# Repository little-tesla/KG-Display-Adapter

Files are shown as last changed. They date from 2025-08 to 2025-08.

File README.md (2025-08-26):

# KG Display Adapter

A KiCAD-designed replacement adapter PCB for Keisoku Giken electronic loads (tested with **ELS-304**, likely compatible with similar models).

## Overview

This adapter allows the use of a modern **3.3V display module** as a replacement for the original LCD.

- **Compatible display:** [NHD-C12864WC-FSW-FBW-3V3](https://www.newhavendisplay.com/nhdc12864wcfswfbw3v3-p-6365.html)
- **Purpose:** Replaces the obsolete LCD

## Important Notes

- The new display is slightly thicker; during assembly, the **thin clear protective sheet** originally in front of the display must be **omitted**.
- The **original backlight LEDs must be removed**.
- The **adapter’s backlight** should be connected using **two wires** to the front panel PCB.

## Images

3D and PCB views of the adapter:

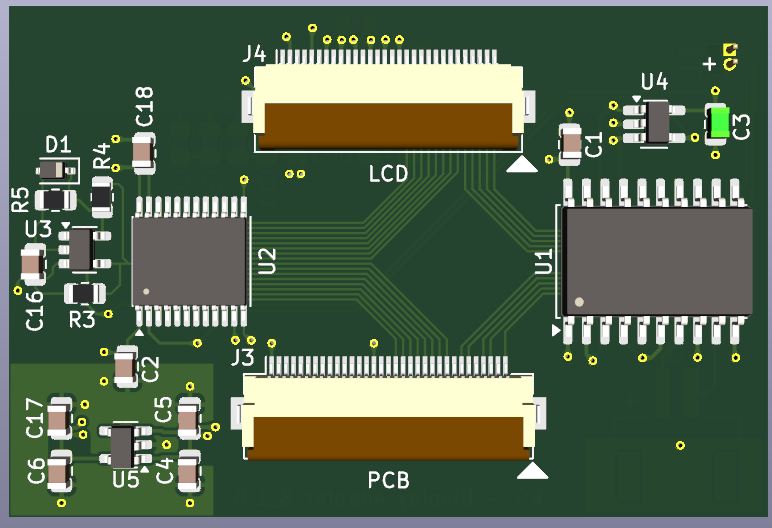
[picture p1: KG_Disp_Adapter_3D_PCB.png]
3D PCB

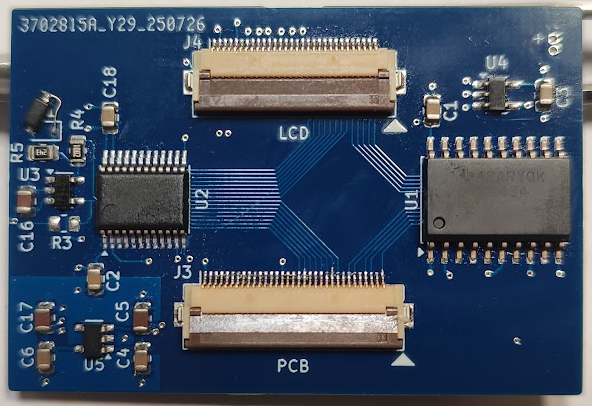
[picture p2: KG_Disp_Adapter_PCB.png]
PCB


Integration and connection to the front panel PCB and display:

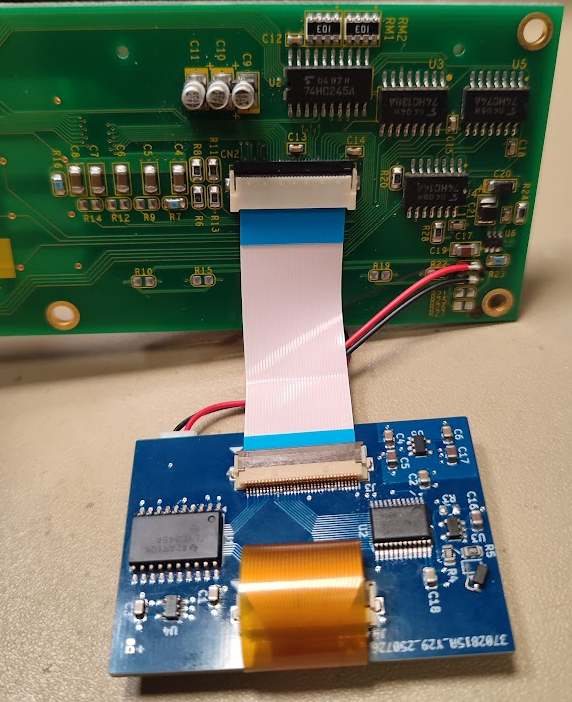
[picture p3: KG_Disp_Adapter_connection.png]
Connection

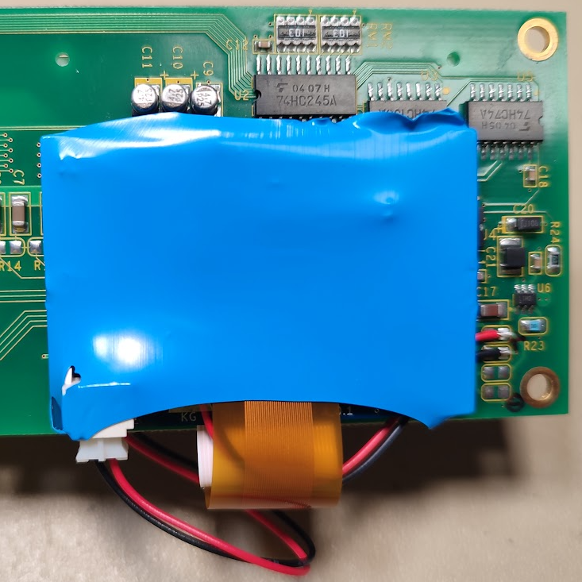
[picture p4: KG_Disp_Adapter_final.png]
Final Assembly


---

This project is shared for educational and hobbyist purposes. Use at your own risk.

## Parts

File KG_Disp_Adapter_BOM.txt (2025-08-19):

"Reference","Value","Datasheet","Footprint","Qty","DNP"
"C1,C2,C3,C4,C6,C18,C19","100n","~","Capacitor_SMD:C_0805_2012Metric","7",""
"C5,C17","10u","~","Capacitor_SMD:C_0805_2012Metric","2",""
"C7,C8,C9,C10,C11,C12,C13,C14,C15","1.5u","~","Capacitor_SMD:C_0805_2012Metric","9",""
"C16","4u7","~","Capacitor_SMD:C_0805_2012Metric","1",""
"D1","D","~","Diode_SMD:D_SOD-323","1",""
"J1","Conn_01x02","~","Connector_PinHeader_1.00mm:PinHeader_1x02_P1.00mm_Horizontal","1",""
"J2","CJT_A2001WR-S-2P_SMT","~","Library:CJT_A2001WR-S-2P_SMT_1x02-1MP_P2.00mm_Horizontal","1",""
"J3","FFC 33Pin, FH12-33S-0.5SH","~","Library:Hirose_FH12-33S-0.5SH_1x33-1MP_P0.50mm_Horizontal_reversed","1",""
"J4","FFC 30Pin, FH12-30S-0.5SH","~","Library:Hirose_FH12-30S-0.5SH_1x30-1MP_P0.50mm_Horizontal_Reversed","1",""
"R1,R2","160","~","Resistor_SMD:R_0805_2012Metric","2",""
"R4","10K","~","Resistor_SMD:R_0805_2012Metric","1",""
"R5","25K","~","Resistor_SMD:R_0805_2012Metric","1",""
"U1","SN74LVC245APW","https://www.ti.com/lit/ds/scas218x/scas218x.pdf","Package_SO:SOIC-20W_7.5x12.8mm_P1.27mm","1",""
"U2","SN74LVC8T245","https://www.ti.com/lit/ds/symlink/sn74lvc8t245.pdf","Package_SO:TSSOP-24_6.1x7.8mm_P0.65mm","1",""
"U3","SN74LVC1G14DBV","https://www.ti.com/lit/ds/symlink/sn74lvc1g14.pdf","Package_TO_SOT_SMD:SOT-23-5","1",""
"U4","NC7SZ32M5X","","Package_TO_SOT_SMD:SOT-23-5_HandSoldering","1",""
"U5","TLV73333PDBV","http://www.ti.com/lit/ds/symlink/tlv733p.pdf","Package_TO_SOT_SMD:SOT-23-5","1",""

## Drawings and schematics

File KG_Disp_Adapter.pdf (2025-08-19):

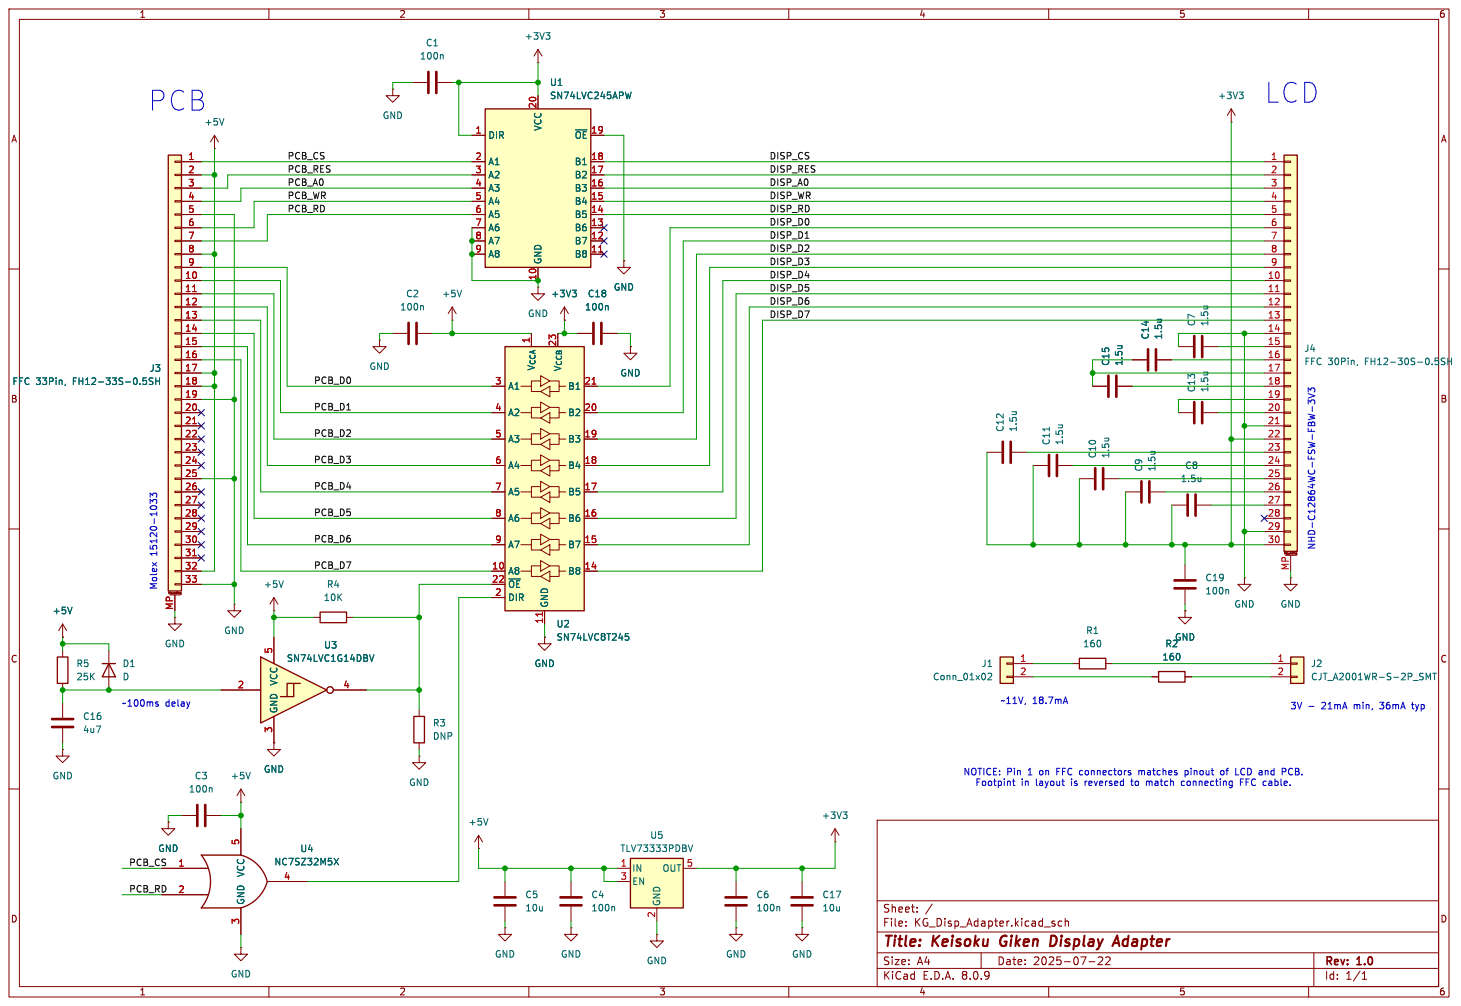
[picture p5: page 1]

Id: 1/1 Title: Keisoku Giken Display Adapter File: KG_Disp_Adapter.kicad_sch Sheet: /

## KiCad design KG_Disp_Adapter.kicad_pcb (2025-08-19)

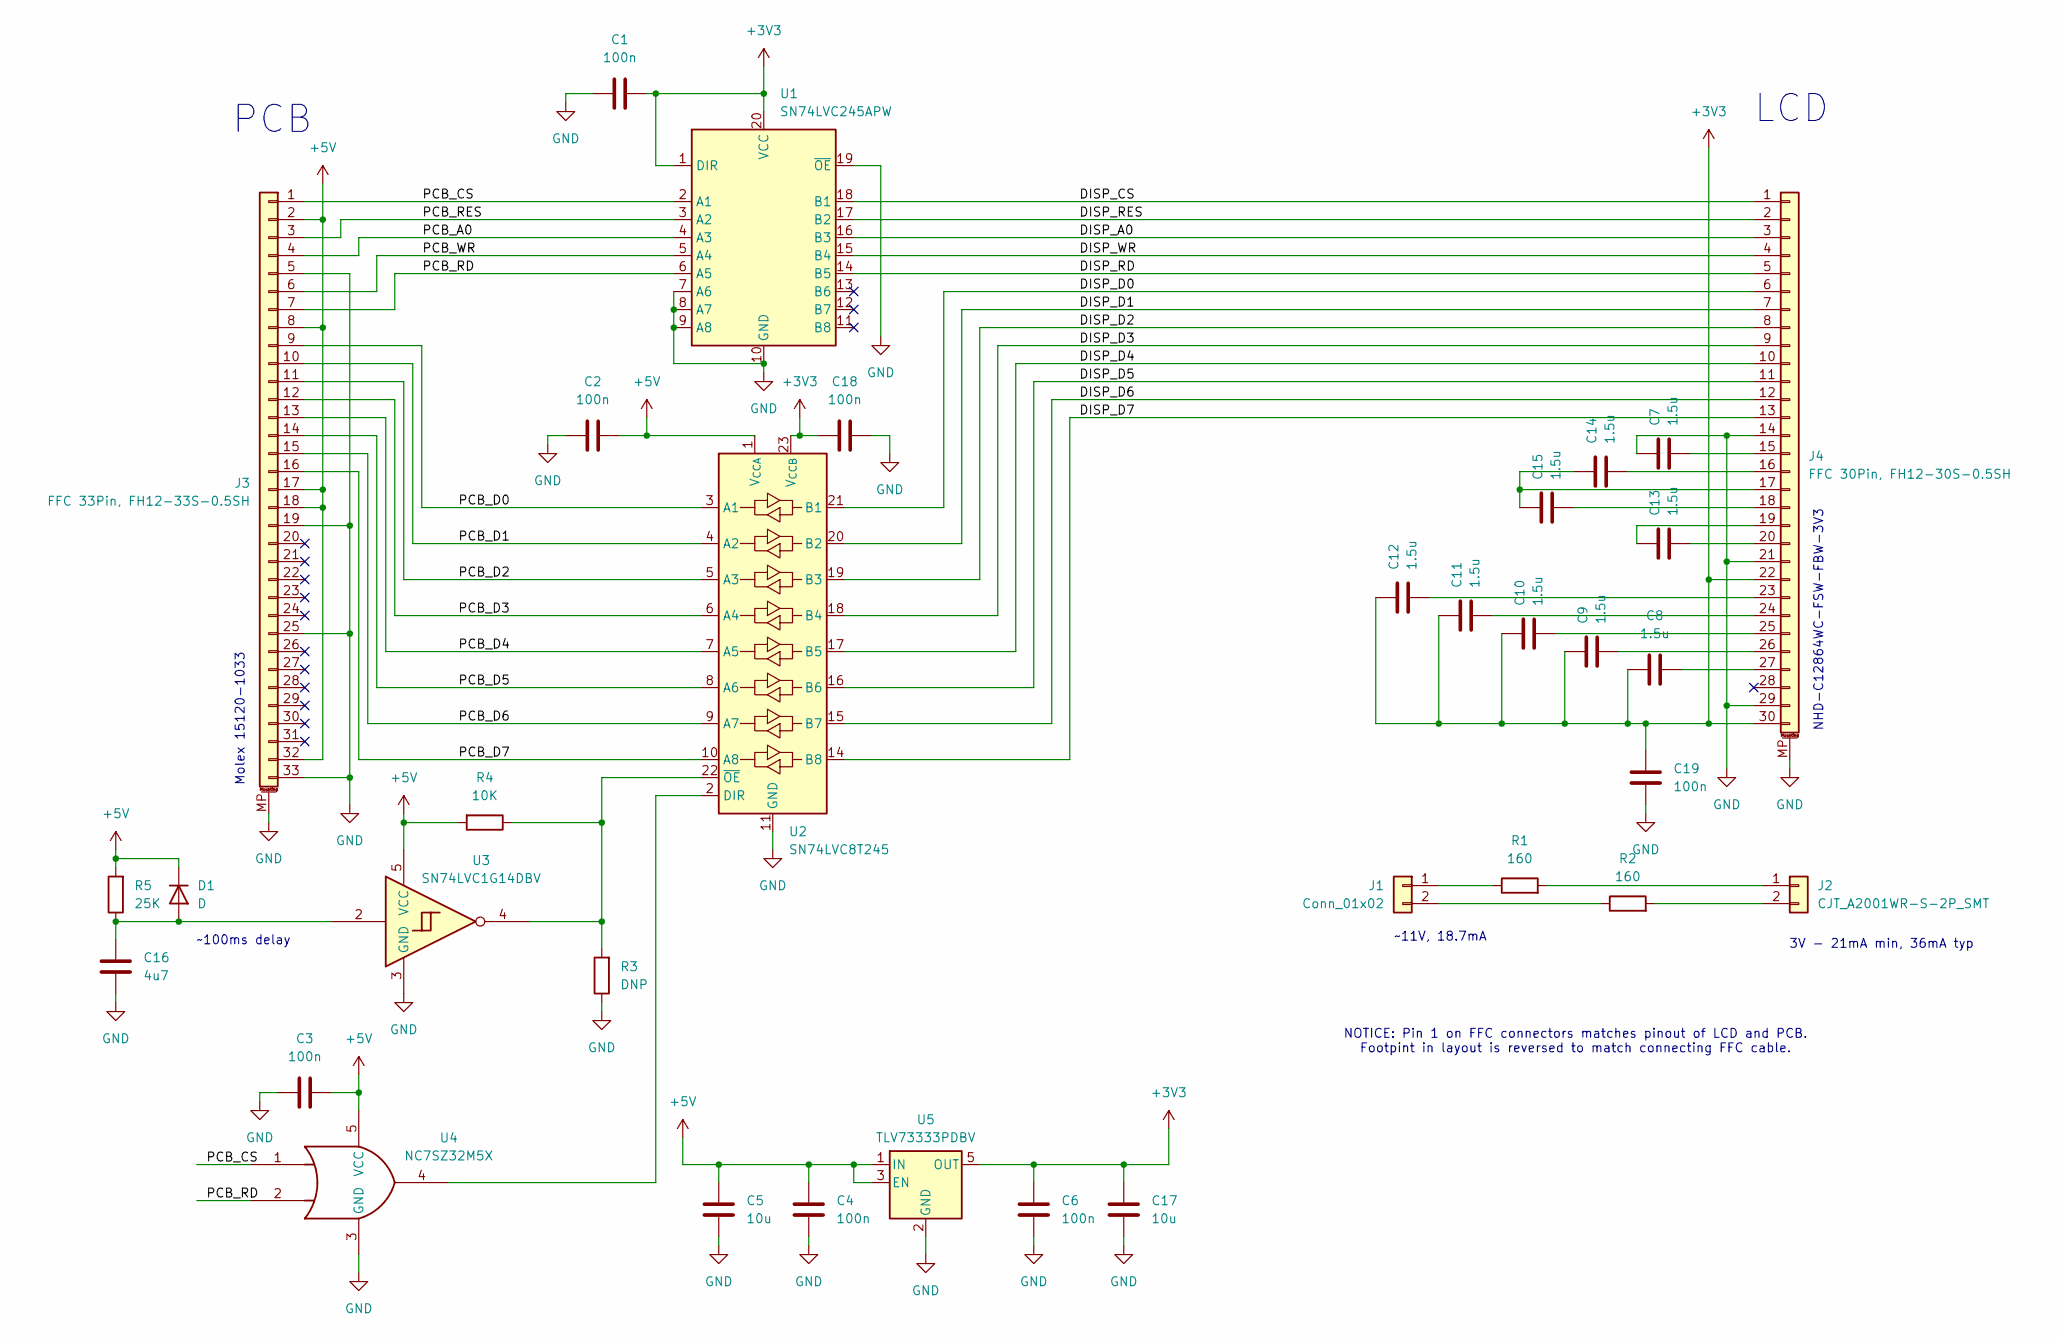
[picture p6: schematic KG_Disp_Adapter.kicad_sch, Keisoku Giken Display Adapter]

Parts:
C1, C2, C3, C4, C6, C18, C19: 100n; C_0805_2012Metric
C5, C17: 10u; C_0805_2012Metric
C7, C8, C9, C10, C11, C12, C13, C14, C15: 1.5u; C_0805_2012Metric
C16: 4u7; C_0805_2012Metric
D1: D; D_SOD-323
J1: Conn_01x02; PinHeader_1x02_P1.00mm_Horizontal
J2: CJT_A2001WR-S-2P_SMT; CJT_A2001WR-S-2P_SMT_1x02-1MP_P2.00mm_Horizontal
J3: FFC 33Pin, FH12-33S-0.5SH; Hirose_FH12-33S-0.5SH_1x33-1MP_P0.50mm_Horizontal_reversed
J4: FFC 30Pin, FH12-30S-0.5SH; Hirose_FH12-30S-0.5SH_1x30-1MP_P0.50mm_Horizontal_Reversed
R1, R2: 160; R_0805_2012Metric
R3: DNP; R_0805_2012Metric
R4: 10K; R_0805_2012Metric
R5: 25K; R_0805_2012Metric
U1: SN74LVC245APW; SOIC-20W_7.5x12.8mm_P1.27mm
U2: SN74LVC8T245; TSSOP-24_6.1x7.8mm_P0.65mm
U3: SN74LVC1G14DBV; SOT-23-5
U4: NC7SZ32M5X; SOT-23-5_HandSoldering
U5: TLV73333PDBV; SOT-23-5

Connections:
+3V3: C1.2, C6.2, C8.1, C9.2, C10.2, C11.2, C12.2, C17.2, C18.1, C19.1, J4.22, J4.30, U1.1 (DIR), U1.20 (VCC), U2.23 (V_{CCB}), U2.24 (V_{CCB}), U5.5 (OUT)
+5V: C2.2, C3.2, C4.2, C5.2, D1.1 (K), J3.2, J3.8, J3.17, J3.18, J3.32, R4.2, R5.2, U2.1 (V_{CCA}), U3.5 (VCC), U4.5 (VCC), U5.1 (IN), U5.3 (EN)
/DISP_A0: J4.3, U1.16 (B3)
/DISP_CS: J4.1, U1.18 (B1)
/DISP_D0: J4.6, U2.21 (B1)
/DISP_D1: J4.7, U2.20 (B2)
/DISP_D2: J4.8, U2.19 (B3)
/DISP_D3: J4.9, U2.18 (B4)
/DISP_D4: J4.10, U2.17 (B5)
/DISP_D5: J4.11, U2.16 (B6)
/DISP_D6: J4.12, U2.15 (B7)
/DISP_D7: J4.13, U2.14 (B8)
/DISP_RD: J4.5, U1.14 (B5)
/DISP_RES: J4.2, U1.17 (B2)
/DISP_WR: J4.4, U1.15 (B4)
/PCB_A0: J3.4, U1.4 (A3)
/PCB_CS: J3.1, U1.2 (A1), U4.1
/PCB_D0: J3.9, U2.3 (A1)
/PCB_D1: J3.10, U2.4 (A2)
/PCB_D2: J3.11, U2.5 (A3)
/PCB_D3: J3.12, U2.6 (A4)
/PCB_D4: J3.13, U2.7 (A5)
/PCB_D5: J3.14, U2.8 (A6)
/PCB_D6: J3.15, U2.9 (A7)
/PCB_D7: J3.16, U2.10 (A8)
/PCB_RD: J3.7, U1.6 (A5), U4.2
/PCB_RES: J3.3, U1.3 (A2)
/PCB_WR: J3.6, U1.5 (A4)
GND: C1.1, C2.1, C3.1, C4.1, C5.1, C6.1, C7.2, C16.1, C17.1, C18.2, C19.2, J3.5, J3.19, J3.25, J3.33, J3.MP (MountPin), J4.14, J4.21, J4.29, J4.MP (MountPin), R3.1, U1.7 (A6), U1.8 (A7), U1.9 (A8), U1.10 (GND), U1.19 (~OE), U2.11 (GND), U2.12 (GND), U2.13 (GND), U3.3 (GND), U4.3 (GND), U5.2 (GND)
unnamed: C16.2, D1.2 (A), R5.1, U3.2
unnamed: J1.1, R1.1
unnamed: J1.2, R2.1
unnamed: J2.1, R1.2
unnamed: J2.2, R2.2
unnamed: C7.1, J4.15
unnamed: C14.1, J4.16
unnamed: C14.2, C15.2, J4.17
unnamed: C15.1, J4.18
unnamed: C13.2, J4.19
unnamed: C13.1, J4.20
unnamed: C12.1, J4.23
unnamed: C11.1, J4.24
unnamed: C10.1, J4.25
unnamed: C9.1, J4.26
unnamed: C8.2, J4.27
unnamed: U2.2 (DIR), U4.4
unnamed: R3.2, R4.1, U2.22 (~OE), U3.4

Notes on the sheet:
NHD-C12864WC-FSW-FBW-3V3
3V - 21mA min, 36mA typ
NOTICE: Pin 1 on FFC connectors matches pinout of LCD and PCB. Footpint in layout is reversed to match connecting FFC cable.
Molex 15120-1033
~100ms delay
LCD
~11V, 18.7mA
PCB

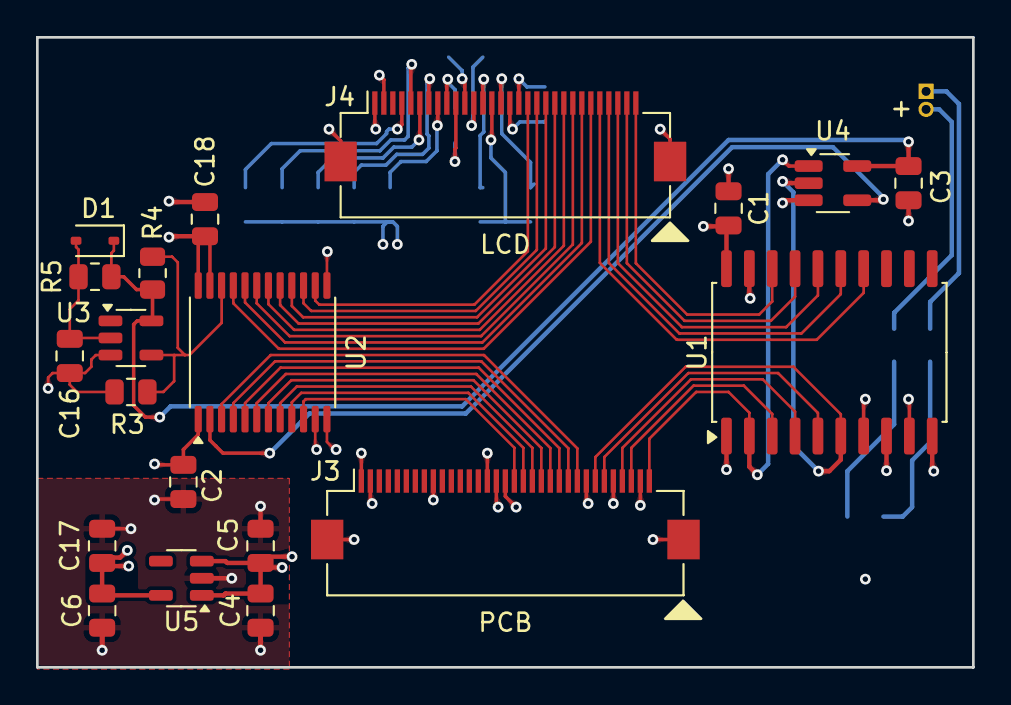
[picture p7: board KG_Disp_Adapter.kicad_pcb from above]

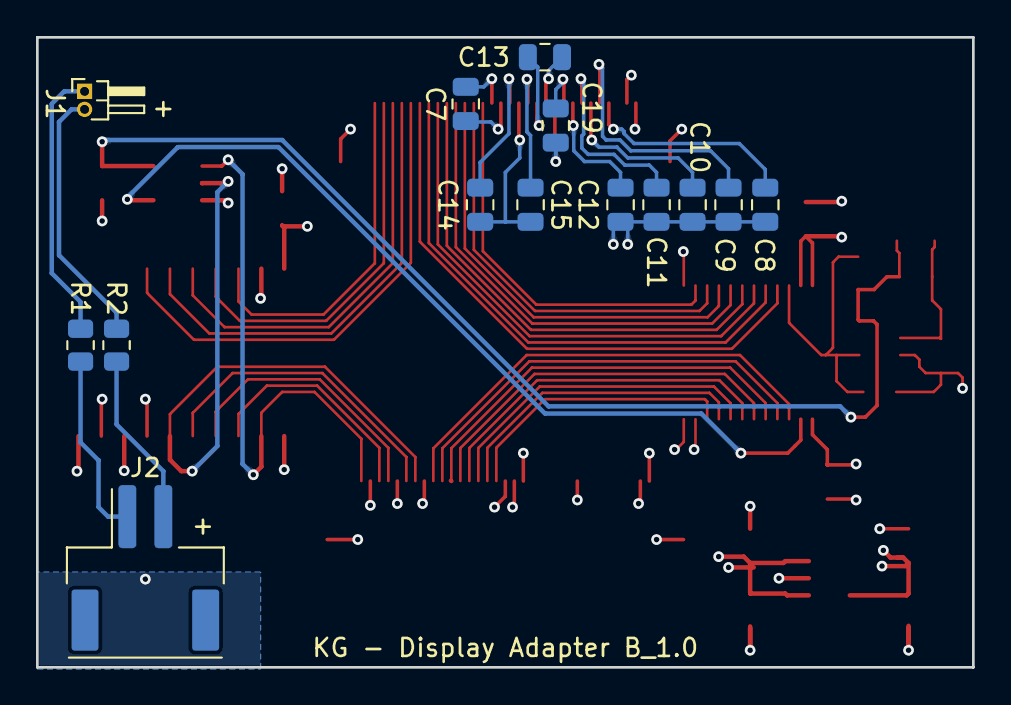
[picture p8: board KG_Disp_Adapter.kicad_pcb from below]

Board: 4 copper layers, 52.0 x 35.0 mm, 34 parts (14 on the bottom side), 47 nets.
